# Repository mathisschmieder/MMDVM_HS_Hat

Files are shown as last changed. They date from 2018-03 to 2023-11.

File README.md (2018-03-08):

# MMDVM_HS_Hat
MMDVM_HS Hat for the Raspberry Pi (Zero)

This project provides a Raspberry Pi Hat for the [MMDVM_HS Hotspot](https://github.com/juribeparada/MMDVM_HS). It was designed for the Raspberry Pi Zero, but should work on any other Pi with the Hat interface. 

First revisions of the board have been built successfully!

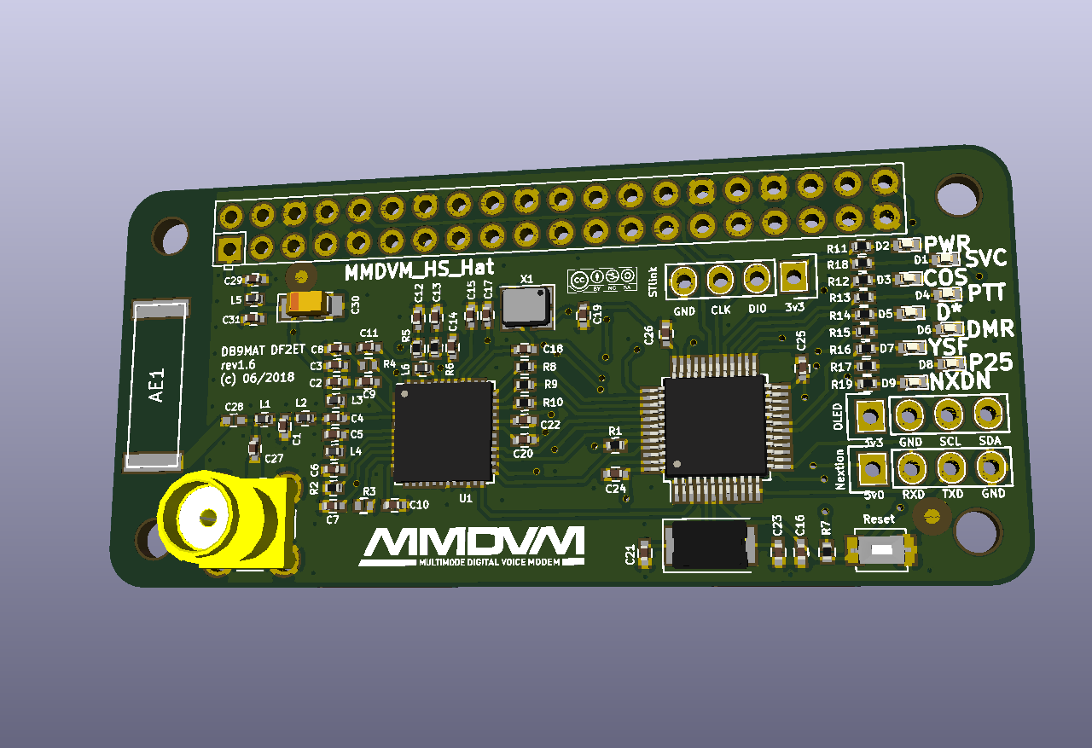
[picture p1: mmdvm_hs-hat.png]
PCB


The PCB is designed in KiCad and the necessary libraries are included. The supplied Gerber files can be used to order PCBs, for example at Elecrow or DirtyPCBs. The board's dimensions are 65x30mm.

You can order 3 beautiful, purple Revision 1.2 PCBs for $15 at [OSHPark](https://oshpark.com/shared_projects/WaiMw5XE)! 

## 3D printed Case

Case

Thanks to Toufik, F0DEI we added the sources for a shiny case that you can print with your 3D printer. It may require a little upscaling depending on your printer model. It can carry a Raspberry Pi Zero (W) with MMDVM_HS_Hat (SMA) on top.

## Revisions
### Revision 0
This was the first released version that still contains a couple of errors. There is a trace missing between L1 and C1 that needs to be fixed with a small blob of solder or magnet wire. Otherwise the RF connector is not connected to the ADF7021. The GND side of C20 and C22 is not connected to the rest of the board's GND, this needs to be fixed with a little wire to any other GND. CE is connected directly to +3.3V which disallows mode scanning to work. If you just use one mode this is fine, otherwise the connection to the CE pin has to be cut and connected to PC14 on the STM32.

Earlier schematics showed C14 as 1uF. This is wrong and needs to be replaced with 1nF, otherwise the ADF7021 will neither receive nor transmit properly.

With these changes, you can build a fully working MMDVM_HS with the old revision 0 boards

### Revision 1
These boards have "Revision 1" written on them. All bugs found in revision 0 are fixed in this version. Apart from that, the STM32's BOOT0 and RESET pins are connected to GPIOs of the Raspberry Pi. This way, flashing should be possible without manually jumpering BOOT0 and triggering a reset.

Component placement did not change between revisions 0 and 1, therefore any stencils for revision 0 should work for revision 1 boards, too.

### Revision 1.1
Rewired 3v3 line for Nextion display connector to 5v0. Added SERVICE LED for visual heartbeat. Fixed improper labelling on P25 and YSF LEDs. Due to added LEDs this revision requires a new stencil.

### Revision 1.2
This Revision adds support for an optional AN1603-443 ceramic antenna. Insert C27 or C28, depending on what kind of antenna you want to use.

### Revision 1.3
The boot jumper was removed and the STlink header moved to its position. This gave space for another 4-pin header allowing to connect I²C OLED displays. No new stencil needed

### Revision 1.4
The SVC LED has been rotated and thus aligned to the layout of all other LEDs. The RainSun ceramic antenna has been replaced by a model that can be ordered at Mouser. DC line filtering has been added to 3v3 line.

### Revision 1.5
A fith mode LED has been added to the board to show NXDN activity. The two pin headers moved downwards a little. The rev1.4 stencil can be re-used if you manually add solder paste to R19 and D9 afterwards.

### Revision 1.6
Inner RX/TX pins of Nextion connector have been swapped. External VCO inductor L6 was added. This is optional for VHF use. D-Star and DMR LEDs were swapped to flash LEDs in proper scan order :).

## BOM
* All necessary parts for the Revision 1.1 board can be ordered at Mouser using the following [shopping cart](http://www.mouser.com/ProjectManager/ProjectDetail.aspx?AccessID=780b8eac44)
* All necessary parts for the Revision 1.2 board can be ordered at Mouser using the following [shopping cart](http://www.mouser.com/ProjectManager/ProjectDetail.aspx?AccessID=035e777242)
* There is also a light version of revision 1.2 without the reset switch, 2.54mm headers and SMA connector [Link](http://www.mouser.com/ProjectManager/ProjectDetail.aspx?AccessID=3f7d0256e1)
* The parts for Revision 1.3 board are in this [Mouser cart](http://www.mouser.com/ProjectManager/ProjectDetail.aspx?AccessID=250d76339b) and the light version is [here](http://www.mouser.com/ProjectManager/ProjectDetail.aspx?AccessID=2d533ac53d)
* [Mouser project](http://www.mouser.com/ProjectManager/ProjectDetail.aspx?AccessID=5cab954f40) for MMDVM_HS_Hat revision 1.4
* There is another [Mouser cart for rev 1.5](https://www.mouser.com/ProjectManager/ProjectDetail.aspx?AccessID=5a3e4ae018).
* And this is the [rev1.6 cart](https://www.mouser.com/ProjectManager/ProjectDetail.aspx?AccessID=48302f4221) and its [light version](https://www.mouser.com/ProjectManager/ProjectDetail.aspx?AccessID=ac888de33a).

Please note that the onboard ceramic antenna is not supplied by Mouser and therefore missing in the carts for revisions up to 1.3.

Either the ADF7021 or the ADF7021-N can be used. Define the proper version in the firmware!

## Firmware Installation

### Compile and upload manually

For specific details about the firmware installation, check [these](https://github.com/juribeparada/MMDVM_HS#build-de-firmware-and-upload-to-zumspot-rpi) instructions. The process is similar to the installation on the ZumSpot Pi. 

Enable the following settings in Config.h:

    #define MMDVM_HS_HAT_REV12
    #define ENABLE_ADF7021
    #define ADF7021_14_7456
    #define STM32_USART1_HOST
    #define ENABLE_SCAN_MODE

Build the firmware:

    make

And finally upload the firmware to the MMDVM_HS_Hat:

    sudo make mmdvm_hs_hat

### Update within Pi-Star

Andy, MW0MWZ was so kind as to add a script which allows for updating the firmware of the MMDVM_HS_Hat within the running Pi-Star system. It uses the pre-compiled binaries from Andy's (CA6JAU) github repository. The update can be done with:

```
$ pistar-zumspotflash hs_hat
```

on the command line.

## Accessoires

* A case for the #MMDVM_HS_Hat can be found at amazon: [Case](https://www.amazon.de/Hochwertiges-schwarzes-auml-uuml-Raspberry/dp/B01FHDXNNU)

* An OLED display also to be found at amazon: [Display](https://www.amazon.de/dp/B01M9JVYIS/ref=cm_sw_r_wa_api_RmZ9zb01APZTV)

## License
This project is released under the Creative Commons Attribution-NonCommercial-ShareAlike 3.0 (CC-BY-NC-SA 3.0, https://creativecommons.org/licenses/by-nc-sa/3.0/) license. You may edit and share it as you like, as long as credit is given and the license is not changed. You can build as many boards for you and your friends as you like and you can even sell it to them to cover your costs, **however it is strictly forbidden to turn this into a commercial product! You are not allowed to build and sell these boards for profit!**

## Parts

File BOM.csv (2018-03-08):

Refs | Value | Footprint | QTY | MFR | MPN | SPR | SPN
SW1 | DNI | Buttons_Switches_SMD:SW_SPST_B3U-1000P | 1 | Omron Electronics | B3U-1000P | Mouser | 653-B3U-1000P
C24;C25;C26;C16;C20;C10;C8;C15;C27;C28;C29 | 100n | Capacitors_SMD:C_0402 | 11 | Vishay / Vitramon | VJ0402V104ZXJCW1BC | Mouser | 77-VJ0402V104ZXJCBC
C22;C7;C9;C2;C17;C19 | 10n | Capacitors_SMD:C_0402 | 6 | Vishay / Vitramon | VJ0402Y103KXJCW1BC | Mouser | 77-VJ0402Y103KXJCBC
C4 | 10p | Capacitors_SMD:C_0402 | 1 | Murata Electronics | GRM1555C1E100GA01D | Mouser | 81-GRM1555C1E100GA1D
C31 | 10u | Capacitors_SMD:C_0402 | 1 | Murata Electronics | GRJ155R60J106ME11D | Mouser | 81-GRJ155R60J106ME1D
C13 | 15n | Capacitors_SMD:C_0402 | 1 | Murata Electronics | GRM155R71C153KA01D | Mouser | 81-GRM155R71C153KA1D
C14 | 1n | Capacitors_SMD:C_0402 | 1 | Murata Electronics | GRM155R60J102KA01D | Mouser | 81-GRM155R60J102KA1D
C21;C23 | 20p | Capacitors_SMD:C_0402 | 2 | Murata Electronics | GJM1555C1H200FB01D | Mouser | 81-GJM1555C1H200FB1D
C3 | 220p | Capacitors_SMD:C_0402 | 1 | Murata Electronics | GRM1555C1H221JA01D | Mouser | 81-GRM1555C1H221JA01
C11 | 22n | Capacitors_SMD:C_0402 | 1 | Murata Electronics | GCM155R71E223KA55D | Mouser | 81-GCM155R71E223KA5D
C18 | 22p | Capacitors_SMD:C_0402 | 1 | AVX | 04025A220GAT2A | Mouser | 581-04025A220G
C12 | 470p | Capacitors_SMD:C_0402 | 1 | Murata Electronics | GRM155R71H471KA01D | Mouser | 81-GRM36X471K50
C5 | 4p7 | Capacitors_SMD:C_0402 | 1 | Murata Electronics | GRM1555C1H4R7CA01D | Mouser | 81-GRM1555C1H4R7CA1D
C6;C1 | 6p8 | Capacitors_SMD:C_0402 | 2 | Murata Electronics | GJM1555C1H6R8BB01D | Mouser | 81-GJM1555C1H6R8BB1D
C30 | 10u/10V | Capacitors_Tantalum_SMD:CP_Tantalum_Case-A_EIA-3216-18_Reflow | 1 | AVX | F931A106KAA | Mouser | 647-F931A106KAA
P3 | SMA | Connectors:SMA_THT_Jack_Straight | 1 | TE Connectivity | 5-1814832-1 | Mouser | 571-5-1814832-1
X1 | TCXO | Crystals:Crystal_SMD_3225-4pin_3.2x2.5mm | 1 | ECS | ECS-TXO-3225-147.4-TR | Mouser | 520-TXO-3225-14.74T
Y1 | 8MHz | Crystals:Crystal_SMD_Abracon_ABM3-2pin_5.0x3.2mm | 1 | ABRACON | ABM3-8.000MHz-D2Y-T | Mouser | 815-ABM3-8-D2Y-T
U1 | ADF7021 | Housings_DFN_QFN:QFN-48-1EP_7x7mm_Pitch0.5mm | 1 | Analog Devices | ADF7021BCPZ | Mouser | 584-ADF7021BCPZ
U2 | STM32F103C8T6 | Housings_QFP:LQFP-48_7x7mm_Pitch0.5mm | 1 | STMicroelectronics | STM32F103C8T6 | Mouser | 511-STM32F103C8T6
L5 | 10u | Inductors_SMD:L_0402 | 1 | Wurth Electronics | 74279277 | Mouser | 710-74279277
L3 | 13n | Inductors_SMD:L_0402 | 1 | Murata Electronics | LQW15AN13NG80D | Mouser | 81-LQW15AN13NG80D
L6 | 18n | Inductors_SMD:L_0402 | 1 | TE Connectivity / Sigma Inductors | 36501E18NJTDG | Mouser | 279-36501E18NJTDG
L2 | 20n | Inductors_SMD:L_0402 | 1 | TE Connectivity / Sigma Inductors | 36501E20NJTDG | Mouser | 279-36501E20NJTDG
L1 | 22n | Inductors_SMD:L_0402 | 1 | Murata Electronics | LQW15CA22NJ00D | Mouser | 81-LQW15CA22NJ00D
L4 | 27n | Inductors_SMD:L_0402 | 1 | Murata Electronics | LQW15AN27NG80D | Mouser | 81-LQW15AN27NG80D
D7 | amber | LEDs:LED_0402 | 1 | Kingbright | APG1005SEC-T | Mouser | 604-APG1005SECT
D9 | blue | LEDs:LED_0402 | 1 | Kingbright | APHHS1005QBC/D | Mouser | 604-APHHS1005QBCD
D2;D5 | green | LEDs:LED_0402 | 2 | Kingbright | APHHS1005CGCK | Mouser | 604-APHHS1005CGCK
D4;D8;D1 | red | LEDs:LED_0402 | 3 | Kingbright | APHHS1005SURCK | Mouser | 604-APHHS1005SURCK
D3;D6 | yellow | LEDs:LED_0402 | 2 | Kingbright | APG1005SYC-T | Mouser | 604-APG1005SYCT
AE1 | CERAMIC_ANTENNA | MMDVM:ANT1204 | 1 | Yageo | ANT1204F002R0433A | Mouser | 603-ANT1204F002R0433
P2 | DISPLAY | Pin_Headers:Pin_Header_Straight_1x04 | 1 | TE Connectivity / AMP | 826629-4 | Mouser | 571-826629-4
P1 | I2C | Pin_Headers:Pin_Header_Straight_1x04 | 1 | TE Connectivity / AMP | 826629-4 | Mouser | 571-826629-4
P4 | STLINK | Pin_Headers:Pin_Header_Straight_1x04 | 1 | TE Connectivity / AMP | 826629-4 | Mouser | 571-826629-4
R1;R7 | 10k | Resistors_SMD:R_0402 | 2 | Vishay | CRCW040210K0FKED | Mouser | 71-CRCW0402-10K-E3
R8;R9;R10;R11;R12;R13;R14;R15;R16;R17;R18;R19 | 1k | Resistors_SMD:R_0402 | 12 | Panasonic | ERJ-PA2D1001X | Mouser | 667-ERJ-PA2D1001X
R2 | 1k1 | Resistors_SMD:R_0402 | 1 | Susumu | RR0510P-112-D | Mouser | 754-RR0510P-112D
R6 | 270 | Resistors_SMD:R_0402 | 1 | Panasonic | ERA-2AEB271X | Mouser | 667-ERA-2AEB271X
R3 | 3k8 | Resistors_SMD:R_0402 | 1 | Susumu | RR0510P-3831-D | Mouser | 754-RR0510P-3831D
R4 | 3r9 | Resistors_SMD:R_0402 | 1 | Vishay | CRCW04023R90JNED | Mouser | 71-CRCW0402J-3.9-E3
R5 | 560 | Resistors_SMD:R_0402 | 1 | Panasonic | ERA-2AEB561X | Mouser | 667-ERA-2AEB561X
PI1 | RPI-ZERO | pizero:RPI-Zero-RASPBERRYPI_BASTELSTUBE_V13_RASPI_BOARD_B+_FULL | 1 | Harwin | M20-7832046 | Mouser | 855-M20-7832046

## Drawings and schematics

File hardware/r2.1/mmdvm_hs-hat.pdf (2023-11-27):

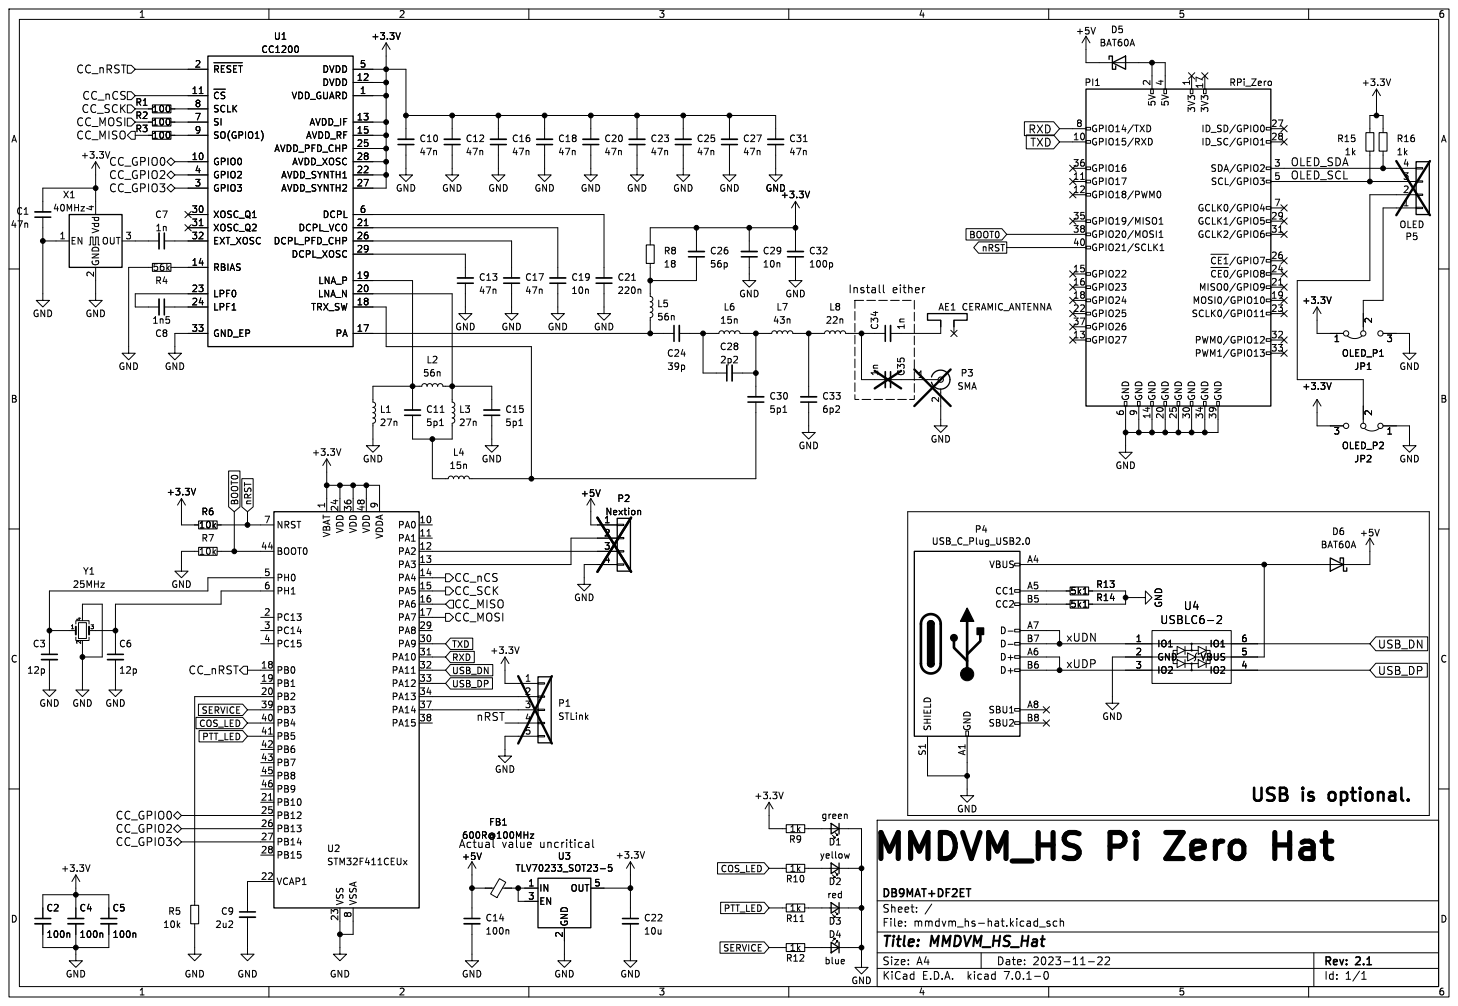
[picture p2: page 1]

1 PA0 10 PA1 11 PA2 12 PA3 13 PA4 14 PA5 15 PA6 16 PA7 17 PB0 18 PB1 19 PC13 2 PB2 20 PB10 21 VCAP1 22 VSS 23 VDD 24 PB12 25 PB13 26 PB14 27 PB15 28 PA8 29 PC14 3 PA9 30 PA10 31 PA11 32 PA12 33 PA13 34 VDD 36 PA14 37 PA15 38 PB3 39 PC15 4 PB4 40 PB5 41 PB6 42 PB7 43 BOOT0 44 PB8 45 PB9 46 VDD 48 PH0 5 PH1 6 NRST 7 VSSA

Id: 1/1 Title: MMDVM_HS_Hat File: mmdvm_hs-hat.kicad_sch Sheet: / DB9MAT+DF2ET

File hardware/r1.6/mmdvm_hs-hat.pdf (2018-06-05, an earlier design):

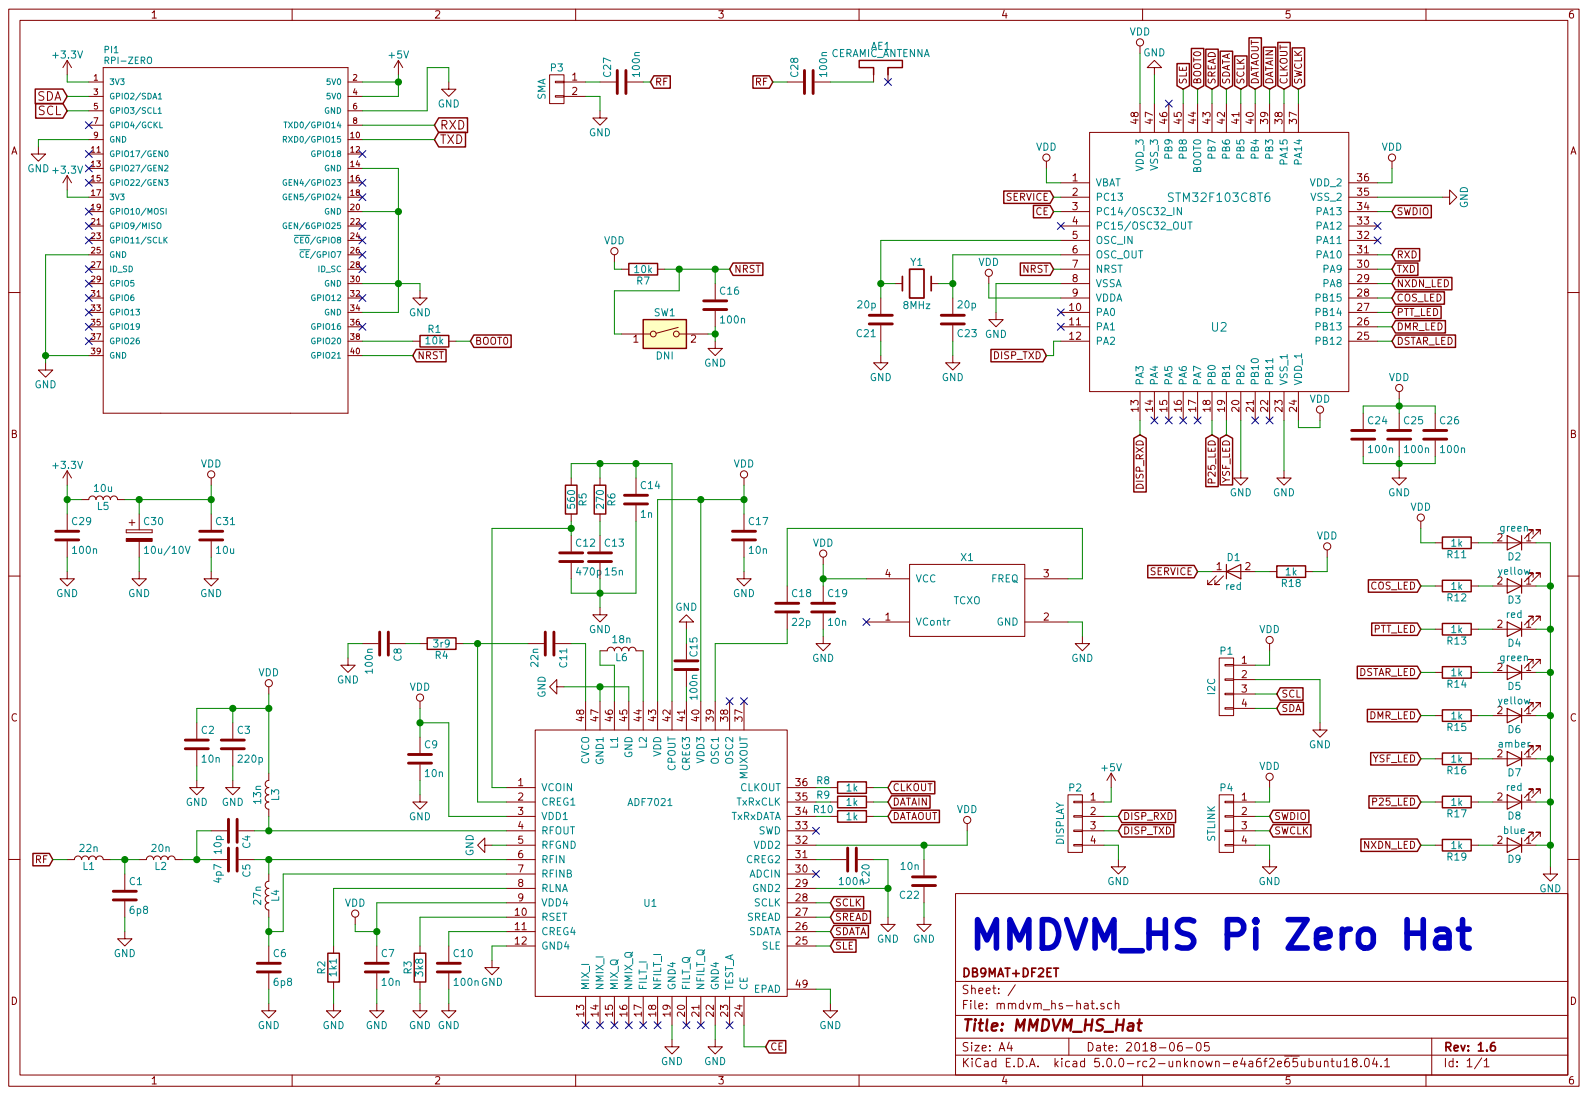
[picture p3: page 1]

File: mmdvm_hs-hat.sch Sheet: / DB9MAT+DF2ET

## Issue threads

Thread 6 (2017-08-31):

Couldn't get revision 1 PCB working

yngwiechou, 2017-08-31:
Hello Mathis,

I purchase a few Revision 1 PCB from Osh Park, and build a MMDV_Hs Pi Hat with RPi3.
Installed a 14.7456 MHz TCXO on it.

I tried to compile and install the ZUMspot RPi software on the MMDVM_HS Pi Hat with RPi3.
But I couldn't get it working properly.

I can see that ADF7021 CLKOUT has continuous clock signal output.
STM32 is working fine.

But it doesn't work with Pi-Star, either using STM32 MMDVM GPIO or ZUMspot GPIO.

I compiled firmware with latest code from MMDVM_HS on GitHub with following parameters:

#define PI_HAT_7021_REV_03
#define ENABLE_ADF7021
#define ADF7021_14_7456
#define STM32_USART1_HOST
#define ENABLE_SCAN_MODE

Is there anything else I should tweak or pay attention to?

Thanks for your help in advance!

Regards,
Yngwie

yngwiechou, 2017-08-31:
I've managed to get it working, thanks!

phl0, 2017-08-31:
What was the issue?

yngwiechou, 2017-09-01:
I think I used the wrong firmware for that.
Need to use the Carrier board one. :)

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

Closed 2017-08-31.

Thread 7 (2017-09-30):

BOM- linked Mouser  Carts

pbepler, 2017-09-30:
in the Mouser shopping cart your readme.md links to there are some incorrect parts:
C 14 -still wrong capacity in cart is 1µF should be 1nF  0402 -correct Nr: 81-GRM155R60J102KA1D
C4 - is size "01005 in" instead of "0402 in" probably confused with "0402mm" value 10pF- correct Nr: 81-GRM1555C1E100JA1D
C8, C10, C15, C16, C20, C24-C28 is size "01005 in" instead of "0402 in" probably confused with "0402mm" value 100nF - correct Nr: 81-GRM022R60J104KE5L

same errors in the revision 1.2 and revision 1.1 carts

phl0, 2017-10-01:
Jepp. Working on that. Hopefully correct by tonight.

phl0, 2017-10-01:
Corrected both rev1.1 and rev1.2 Mouser carts.

Closed 2017-10-01.

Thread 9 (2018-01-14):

Two Boards... same issue.

WC6Q, 2018-01-14:
HI!,
So I built two of the 1.2 boards. After flashing the firmware I tried both and everything works except for that there is no audio, and when I transmit to the boards nothing happens. I have doubled checked settings, such as frequency and the basic stuff. I have also verified that the components are oriented correctly.
Any ideas what would cause such an issue? Or just a direction I should go? I am amazed both are acting the same way.

Thanks for your help and insight into my problem.

73,
Ryan
WC6Q

phl0, 2018-01-14:
What do the LEDs say? Did you enable scan mode in the firmware? Are the mode LEDs blinking one after another when MMDVMHost is running?

WC6Q, 2018-01-14:
LEDs were not circling, had power LED and a slow, then fast service LED. I checked the Config.h and sure enough none of the settings were right. (I switched to an older SD card and forgot to check that) Once I fixed Config.h everything came to life! Thank you for responding, and thanks for your help on this project. It's been fun! 73!! Ryan_WC6Q

phl0, 2018-01-14:
Well congrats then. :+1:

Closed 2018-01-14.

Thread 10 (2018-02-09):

Any plan change the footprint to 0805?

jcyfkimi, 2018-02-09:
Dear Sir
         Currently 0402 footprint is too small for hand soldering and I want to know any plan of change it to 0805?

mathisschmieder, 2018-02-09:
Sorry, we don't have any plans to change the footprints to 0805 for several reasons. There would not be enough space on the board to use 0805 components. Besides, the ADF7021 is much harder to solder than 0402 components. There is a 0603 branch, but the ADF7021 still requires quite a bit soldering expertise.

Closed 2018-02-09.

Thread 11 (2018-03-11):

The new revision's SMA antenna doesn't line up with available cases

jberry, 2018-03-11:
Would it be possible to generate a Kicad with the SMA in the original location (where the Ceramic antenna is now), so that we have the option of printing a rev 1.6 that is compatible with other hotspot cases?

phl0, 2018-03-11:
We had to relocate the SMA socket due to more added components and thus the space between the two screw holes had to be used optimally. Placing the SMA socket there wasted too much space.

jberry, 2018-03-12:
Ah, makes sense on the space usage, but glad to hear it should be feasible. I didn't see many components that appear to be in the way besides antenna + C28 and maybe C31.  I'll fireup KiCad and see what I can work up, always been an Eagle user =)

phl0, 2018-03-12:
I guess it should be feasible. Especially if you then just leave out the SMD onboard antenna and only move the SMA connector.

jberry, 2018-03-12:
Yeah, that's the plan, only do the SMA. Seems only that 1 thingiverse case has adopted the new antenna location (at least looking for mmdvm or zumspot searches), and 1 looks to be for ceramic only (even though it could be drilled out); a lot of the others, including nice metal cases such as https://i.ebayimg.com/images/g/2qcAAOSwDVtacnJC/s-l500.jpg , require the old SMA location.

Closed 2018-03-12.

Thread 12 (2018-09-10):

BOM - More Specific Values

szechyjs, 2018-09-10:
I noticed that the BOM csv/xls list values (resistance, capacitance, etc) for passive components however they do not list tolerances and power ratings. Obviously the listed part numbers have these values associated with them, but it would be nice to know what parameters are required for each component.

For example I have a bunch of 1k 1% resistors in my stock, however the part listed for R19 has a 0.5% tolerance. Having a more detailed BOM would help identify if these types of substitutions can be made.

dd5xl, 2019-01-03:
Treat the supplied BoM as an example.
For the MMDVM-Hat it actually doesn't matter to distinguish between 1% and 0,5% tolerated components, this is a ham radio project, not a life-time-calibrated measureing device.

Closed 2019-02-07.

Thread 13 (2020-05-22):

Board Licensing OSHW vs CC BY-NC-SA License

Shadyman, 2020-05-22:
Thanks for designing such an amazing board.

(Similar: [MMDVM_HS_Dual_Hat Issue 5](https://github.com/phl0/MMDVM_HS_Dual_Hat/issues/5) but mostly copied here as it applies as well)

I noticed you have the board under CC-BY-NC-SA, which (while also my license of choice), means it can't be considered Open Source Hardware by OSHW Association standards, as the "Non-Commercial" clause isn't allowed in OSHW-logo products.

(I'm only mentioning it because I was considering designing-in part of your board into my project and wanted to know which i needed to apply. I'm more than fine with CC BY-NC-SA)

To keep it under CC-BY-NC-SA, you may want to remove the gear logo to be compliant with their rules.

For more information:
https://www.oshwa.org/wp-content/uploads/2014/08/Open-Source-Hardware-Checklist-1.pdf
https://www.oshwa.org/wp-content/uploads/2014/08/OSHW-May-and-Must.pdf

73 from VE3-land de Matthew

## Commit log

2017-05-22 Initial commit of KiCad files
    [mmdvm_hs-hat.kicad_pcb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]
2017-05-22 Added Bill of Materials
    [BOM.csv, BOM.xlsx]
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2017-06-20 Fixed connection between C1 and L2
    [mmdvm_hs-hat.kicad_pcb]
2017-06-21 Added wires for FW flashing
    [mmdvm_hs-hat.kicad_pcb, mmdvm_hs-hat.sch]
2017-06-21 Add BOM infos and update files
    [BOM.csv, BOM.xlsx, mmdvm_hs-hat.sch]
2017-07-06 Fixed Loop Filter; Added CE GPIO
    [mmdvm_hs-hat.kicad_pcb, mmdvm_hs-hat.sch]
2017-07-06 Rerouted CE pin
    [mmdvm_hs-hat.kicad_pcb, mmdvm_hs-hat.sch]
2017-07-06 Removed unnecessary resistors in RX/TX line
    [mmdvm_hs-hat.kicad_pcb, mmdvm_hs-hat.sch]
2017-07-09 Revision 1: Fixed error in STM32 pin description; Reassigned CE to PC14
    [mmdvm_hs-hat.kicad_pcb, mmdvm_hs-hat.sch]
2017-07-09 Updated Gerbers to Revision 1
    [mmdvm_hs-hat.kicad_pcb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]
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2017-07-12 Updated BOM to Revision 1
    [BOM.csv, BOM.xlsx]
2017-07-25 Switch Nextion header from 3v3 to 5v0
    [mmdvm_hs-hat.kicad_pcb, mmdvm_hs-hat.sch]
2017-07-25 Add another LED for SERVICE. Fix YSF/P25 labelling
    [BOM.csv, BOM.xlsx, mmdvm_hs-hat.kicad_pcb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]
2017-07-25 Add pin description (display) and replace picure
    [mmdvm_hs-hat.kicad_pcb]
2017-07-25 Label STlink pin header and update (c)
    [mmdvm_hs-hat.kicad_pcb]
2017-07-26 Beautified descriptions; Updated picture
    [mmdvm_hs-hat.kicad_pcb]
2017-07-26 Updated gerber files to Revision 1.1
    [mmdvm_hs-hat-B.Cu.gbl, mmdvm_hs-hat-B.Mask.gbs, mmdvm_hs-hat-B.Paste.gbp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]
2017-07-26 Replaced SMA jack
    [BOM.csv, BOM.xlsx, mmdvm_hs-hat.sch]
2017-07-26 Re-annotate schematic, replace LEDs and resistors
    [BOM.csv, BOM.xlsx, mmdvm_hs-hat.kicad_pcb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]
2017-07-26 Added more GND vias
    [mmdvm_hs-hat.kicad_pcb]
2017-07-26 Rotated LEDs and exchanged for 20mA types
    [BOM.csv, BOM.xlsx, mmdvm_hs-hat.kicad_pcb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]
2017-08-14 Change resistor values back to 1k
    [BOM.csv, BOM.xlsx]
2017-08-16 Move component identifiers
    [mmdvm_hs-hat-B.Cu.gbl, mmdvm_hs-hat-B.Mask.gbs, mmdvm_hs-hat-B.Paste.gbp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]
2017-08-16 Update PDF of schematic
    [mmdvm_hs-hat.sch]
2017-08-23 Fixed Outline
    [mmdvm_hs-hat.kicad_pcb]
2017-08-23 Revision 1.2: Add AN1603-433 chip antenna
    [mmdvm_hs-hat.kicad_pcb, mmdvm_hs-hat.sch]
2017-08-25 Fixed GND under chip antenna
    [mmdvm_hs-hat.kicad_pcb, mmdvm_hs-hat.sch]
2017-08-25 Minor beautification
    [mmdvm_hs-hat.kicad_pcb]
2017-08-30 Updated Gerbers to Revision 1.2
    [mmdvm_hs-hat-B.Cu.gbl, mmdvm_hs-hat-B.Mask.gbs, mmdvm_hs-hat-B.Paste.gbp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]
2017-08-30 Fixed Revision 1.2 Gerbers
    [mmdvm_hs-hat-B.Cu.gbl, mmdvm_hs-hat-B.Mask.gbs, mmdvm_hs-hat-B.Paste.gbp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]
2017-08-31 Refactor BOM to latest revision
    [BOM.csv, BOM.xlsx, mmdvm_hs-hat.sch]
2017-09-23 Correct part no for C14
    [BOM.csv, BOM.xlsx]
2017-10-01 Correct case dimensions for 01005 parts
    [BOM.csv, BOM.xlsx, mmdvm_hs-hat.sch]
2017-10-06 Add lib and footprint for AN1603
    [mmdvm_hs-hat.kicad_pcb, mmdvm_hs-hat.sch]
2017-10-22 Change footprint for C27/28 to 0603 and update BOM
    [BOM.csv, BOM.xlsx, mmdvm_hs-hat.kicad_pcb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]
2017-11-02 Removed accidentially grounded GPIOs
    [mmdvm_hs-hat.kicad_pcb, mmdvm_hs-hat.sch]
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2017-11-04 Update to 1.3 add OLED pin header / remove boot jumper
    [mmdvm_hs-hat.kicad_pcb, mmdvm_hs-hat.sch]
2017-11-04 Update BOM for rev1.3
    [BOM.csv, mmdvm_hs-hat.sch]
2017-11-04 Add Mouser carts for rev1.3 and export BOM to xlsx
    [BOM.xlsx]
2017-11-04 Update gerber files for rev1.3
    [mmdvm_hs-hat-B.Cu.gbl, mmdvm_hs-hat-B.Mask.gbs, mmdvm_hs-hat-B.Paste.gbp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]
2017-11-10 Preparing for Yageo ceramic antenna
    [mmdvm_hs-hat.sch]
2017-11-10 Revision 1.4: Power filtering, Different ceramic antenna
    [mmdvm_hs-hat.kicad_pcb, mmdvm_hs-hat.sch]
2017-11-10 Edit visibility of P1,2,4 descriptions
    [mmdvm_hs-hat.kicad_pcb]
2017-11-10 Rerouted some VDD wires
    [mmdvm_hs-hat.kicad_pcb]
2017-11-10 Update project meta data
    [mmdvm_hs-hat.kicad_pcb, mmdvm_hs-hat.sch]
2017-11-10 Update BOM and README for rev1.4
    [BOM.csv, BOM.xlsx, mmdvm_hs-hat.sch]
2017-11-10 Re-added OSHW logo
    [mmdvm_hs-hat.kicad_pcb]
2017-11-13 Update gerber files to rev1.4
    [mmdvm_hs-hat-B.Cu.gbl, mmdvm_hs-hat-B.Mask.gbs, mmdvm_hs-hat-B.Paste.gbp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]
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2018-01-02 Update BOM and Mouser cart for rev1.4 board batch
    [BOM.csv, BOM.xlsx, mmdvm_hs-hat.kicad_pcb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]
2018-01-25 Add NXDN LED
    [mmdvm_hs-hat.kicad_pcb, mmdvm_hs-hat.sch]
2018-01-25 Update README and BOM to rev1.5
    [BOM.csv, BOM.xlsx, mmdvm_hs-hat.sch]
2018-02-08 Add fiducials and set origin
    [mmdvm_hs-hat-B.Cu.gbl, mmdvm_hs-hat-B.Mask.gbs, mmdvm_hs-hat-B.Paste.gbp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]
2018-02-09 Realign left fiducial
    [mmdvm_hs-hat-B.Cu.gbl, mmdvm_hs-hat-B.Mask.gbs, mmdvm_hs-hat-B.Paste.gbp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]
2018-02-09 Move origin to moved fiducial
    [mmdvm_hs-hat.kicad_pcb]
2018-02-09 Make SW1 pads excluded from F Paste layer
    [mmdvm_hs-hat-B.Cu.gbl, mmdvm_hs-hat-B.Mask.gbs, mmdvm_hs-hat-B.Paste.gbp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]
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2018-03-02 Add rev1.6 with swapped RX/TX pins on NXT header and add L6 (optional)
    [BOM.csv, BOM.xlsx, mmdvm_hs-hat.kicad_pcb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]
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2018-03-06 Rearrange logos and text
    [mmdvm_hs-hat.kicad_pcb, mmdvm_hs-hat.sch]
2018-03-08 Swap D-Star and DMR LED
    [BOM.csv, BOM.xlsx, mmdvm_hs-hat.kicad_pcb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]
2018-03-28 Re-arrange labels for L3 and L4
    [mmdvm_hs-hat.kicad_pcb]
2018-06-05 Add info table for used TCXO frequency
    [mmdvm_hs-hat.kicad_pcb, mmdvm_hs-hat.sch]
2018-06-05 Remove outdated gerber files
    [mmdvm_hs-hat-B.Cu.gbl, mmdvm_hs-hat-B.Mask.gbs, mmdvm_hs-hat-B.Paste.gbp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]
2020-07-15 Clean up
    Moved kicad files to hardware/r1.6
    Removed most custom libraries & footprints
    [mmdvm_hs-hat.kicad_pcb, mmdvm_hs-hat.sch]
2020-07-15 Tentative revision 2.0 schematics
    [mmdvm_hs-hat.kicad_pcb, mmdvm_hs-hat.sch]
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2020-07-17 Initial routing done for rev2.0
    [mmdvm_hs-hat.kicad_pcb, mmdvm_hs-hat.sch]
2020-08-17 Small silk screen changes
    Final Revision 2.0, tested and working
    [mmdvm_hs-hat.kicad_pcb, mmdvm_hs-hat.sch]
2023-11-23 Very initial WIP CC1200/STM32F4 commit
    [mmdvm_hs-hat.kicad_pcb, mmdvm_hs-hat.kicad_sch, mmdvm_hs-hat.sch]
2023-11-24 Initial routing of r2.1
    [mmdvm_hs-hat.kicad_pcb, mmdvm_hs-hat.kicad_sch]
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2023-11-27 r2.1 RC2
    Re-worked USB resistors, changed some labels, added vias
    [mmdvm_hs-hat.kicad_pcb, mmdvm_hs-hat.kicad_sch]
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
